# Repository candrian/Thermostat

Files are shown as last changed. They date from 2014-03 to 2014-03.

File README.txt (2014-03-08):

In the need of my new homemade energy saving fireplace (which boils water for the radiator) i designed and built a digital thermostat. The idea to design my own thermostat came when i came across with the following problem.
When i first fire the fireplace the water in the boiler around the fireplace is cool. After a few minutes the fireplace warms the water enough so that the water temp exceeds the thermostat limit. The thermostat changes state and drives an electric valve to move the water from the fireplace boiler to the radiators. The electric valve is slow enough and takes a few minutes to make a full turn. While the water is moving from the fireplace boiler to the radiators, circularly cool water is coming back in the fireplace boiler from the radiators. Τhe water temp in the fireplace boiler is getting cooler and after a few minutes falls under thermostat's limit. The thermostat changes state and stops the valve from driving the water to radiators. This happens again and again until the whole amount of water in the radiators is get warm. 
To prevent this problem from opening and closing the electric valve in so small time spaces i designed a thermostat that can delay the sample points. It check's the fireplace boiler temp and drives the electric valve once the water temp exceeds the thermostat limit. After that it waits for a half hour or more and then checks the water temp again.

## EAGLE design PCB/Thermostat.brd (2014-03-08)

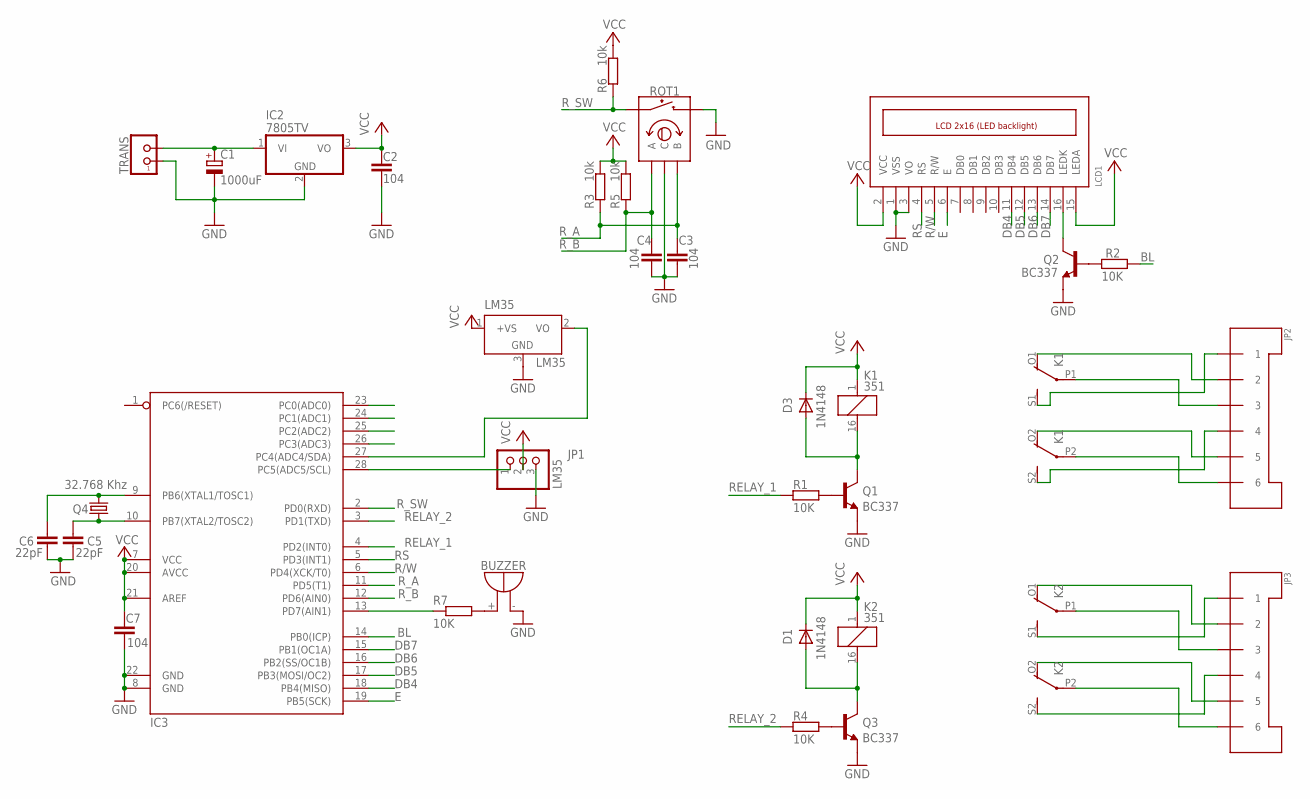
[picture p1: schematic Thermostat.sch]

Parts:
BUZZER: F/HMB
C1: 1000uF; C-TT2D13-SIDE
C2, C3, C4, C7: 104; C-22X6(FAKI)
C5, C6: 22pF; C-22X6(FAKI)
D1, D3: 1N4148; DO35-10
IC2: 7805TV; TO220V
IC3: ATMEGA-8-P; DIL28-3
JP1: LM35; 1X03
JP2, JP3: KLEMES_DELMAC_6
K1, K2: 351
LCD1: LCD-HD44780PINHEAD; HD44780-2X16-PINHEAD
LM35: LM35; TO-92
Q1, Q2, Q3: BC337; TO92-EBC
Q4: 32.768 Khz; TC38
R1, R2, R4, R7: 10K; R0270/10
R3, R5, R6: 10k; R0270/10
ROT1: ROTARY/5-PIN; 5-PIN/RP
TRANS: KLEMESX2

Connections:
BL: IC3.14 (PB0(ICP)), R2.2
DB4: IC3.18 (PB4(MISO)), LCD1.11 (DB4)
DB5: IC3.17 (PB3(MOSI/OC2)), LCD1.12 (DB5)
DB6: IC3.16 (PB2(SS/OC1B)), LCD1.13 (DB6)
DB7: IC3.15 (PB1(OC1A)), LCD1.14 (DB7)
E: IC3.19 (PB5(SCK)), LCD1.6 (E)
GND: BUZZER.-, C1.-, C2.2, C3.2, C4.2, C5.2, C6.2, C7.2, IC2.2 (GND), IC3.8 (GND), IC3.22 (GND), JP1.3, LCD1.1 (VSS), LCD1.3 (VO), LM35.3 (GND1), Q1.E, Q2.E, Q3.E, ROT1.C, ROT1.SW2, TRANS.1
unnamed: JP2.P$3 (3), K1.P1
unnamed: JP3.P$2 (2), K2.O1 (O)
unnamed: C1.+, IC2.1 (VI), TRANS.2
unnamed: D1.A, K2.16 (2), Q3.C
unnamed: C5.1, IC3.10 (PB7(XTAL2/TOSC2)), Q4.1
unnamed: Q3.B, R4.2
unnamed: JP3.P$6 (6), K2.P2
unnamed: BUZZER.+, R7.2
unnamed: IC3.13 (PD7(AIN1)), R7.1
unnamed: IC3.28 (PC5(ADC5/SCL)), JP1.1
unnamed: LCD1.16 (LEDK), Q2.C
unnamed: C6.1, IC3.9 (PB6(XTAL1/TOSC1)), Q4.2
unnamed: Q2.B, R2.1
unnamed: D3.A, K1.16 (2), Q1.C
unnamed: Q1.B, R1.2
unnamed: JP2.P$6 (6), K1.P2
unnamed: JP2.P$1 (1), K1.S1 (S)
unnamed: JP2.P$5 (5), K1.O2 (O)
unnamed: JP2.P$4 (4), K1.S2 (S)
unnamed: JP2.P$2 (2), K1.O1 (O)
unnamed: JP3.P$1 (1), K2.S1 (S)
unnamed: JP3.P$3 (3), K2.P1
unnamed: JP3.P$5 (5), K2.O2 (O)
unnamed: JP3.P$4 (4), K2.S2 (S)
unnamed: IC3.27 (PC4(ADC4/SDA)), LM35.2 (VO)
R/W: IC3.6 (PD4(XCK/T0)), LCD1.5 (R/W)
RELAY_1: IC3.4 (PD2(INT0)), R1.1
RELAY_2: IC3.3 (PD1(TXD)), R4.1
RS: IC3.5 (PD3(INT1)), LCD1.4 (RS)
R_A: C3.1, IC3.11 (PD5(T1)), R3.1, ROT1.B
R_B: C4.1, IC3.12 (PD6(AIN0)), R5.1, ROT1.A
R_SW: IC3.2 (PD0(RXD)), R6.1, ROT1.SW1
VCC: C2.1, C7.1, D1.C, D3.C, IC2.3 (VO), IC3.7 (VCC), IC3.20 (AVCC), IC3.21 (AREF), JP1.2, K1.1, K2.1, LCD1.2 (VCC), LCD1.15 (LEDA), LM35.1 (+VS), R3.2, R5.2, R6.2

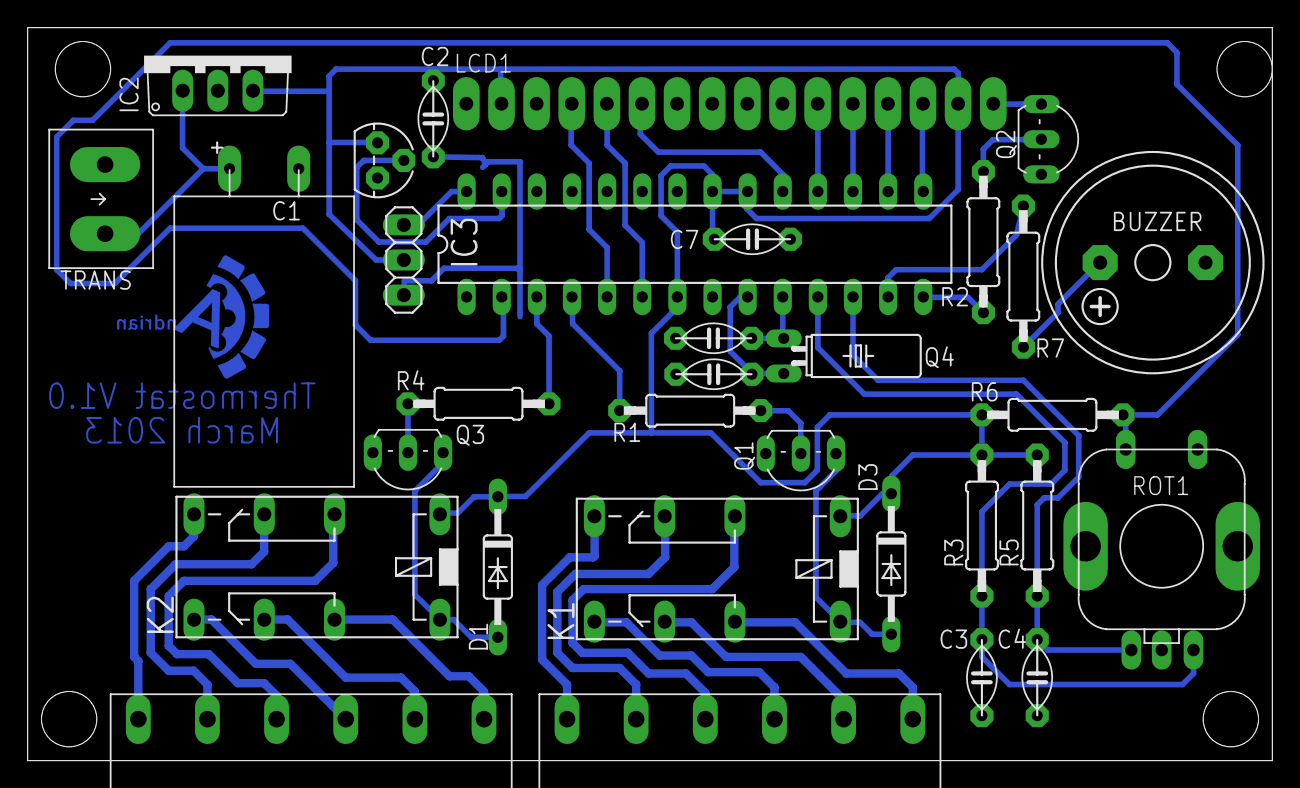
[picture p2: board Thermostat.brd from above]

Board: 2 copper layers, 90.0 x 53.0 mm, 33 parts (0 on the bottom side), 40 nets.

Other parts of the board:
U$1: CANDRIAN-LOGO/SMALL/BOTTOM

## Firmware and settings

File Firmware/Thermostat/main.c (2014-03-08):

/*
Thermostat
(c) Created by candrian on 3/27/13.

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
THE SOFTWARE IS PROVIDED "AS IS", WITHOUT WARRANTY OF ANY KIND, EXPRESS OR
IMPLIED, INCLUDING BUT NOT LIMITED TO THE WARRANTIES OF MERCHANTABILITY,
FITNESS FOR A PARTICULAR PURPOSE AND NONINFRINGEMENT. IN NO EVENT SHALL THE
AUTHORS OR COPYRIGHT HOLDERS BE LIABLE FOR ANY CLAIM, DAMAGES OR OTHER
LIABILITY, WHETHER IN AN ACTION OF CONTRACT, TORT OR OTHERWISE, ARISING FROM,
OUT OF OR IN CONNECTION WITH THE SOFTWARE OR THE USE OR OTHER DEALINGS IN
THE SOFTWARE.
*/

#include <avr/io.h>
#include <stdint.h>
#define F_CPU 8000000UL
#include <util/delay.h>     // Blocking delay functions
#include <avr/pgmspace.h>   // So we can store the 'font table' in ROM
#include <avr/interrupt.h>	// Interrupts and timers
#include <avr/eeprom.h>		// Date/time/pref backup in permanent EEPROM
#include <avr/sleep.h>      // Power save mode
#include <avr/wdt.h>


#include "main.h"

#include "lcd.h"
#include "lcd.c"

volatile    uint8_t minutes_set=0;
volatile    uint8_t hours_set=0;

volatile    uint8_t in_temp_set=0;
volatile    uint8_t pipe_temp_set=0;

volatile    uint16_t in_temp=0;
volatile    uint16_t pipe_temp=0;

volatile    uint8_t     rotary_state=NOTHING;
volatile    uint16_t    rotary_press_time=0;

volatile    uint8_t     menu_edit=OFF;

volatile    uint8_t     counter=0;
volatile    uint8_t     timer=OFF;

volatile    uint8_t     menu_timeout=0;
volatile    uint8_t     backlight_timeout=0;
volatile    uint8_t     backlight=ON;

volatile    uint8_t     in_temp_buffer[10];
volatile    uint8_t     pipe_temp_buffer[10];

volatile    uint8_t     buffer_pointer=0;

volatile    uint8_t     relay_pipe=OFF;
volatile    uint8_t     relay_in=OFF;


uint16_t adc_read(uint8_t sensor){
    ADMUX &= 0xf0;
    if (sensor==IN) {
        ADMUX   |=  (1<<MUX2);
    }else{
        ADMUX   |=  (1<<MUX2) | (1<<MUX0);
    }
    
    _delay_ms(1);
    ADCSRA  |=  _BV(ADSC);          //Start single conversion
    while(ADCSRA & _BV(ADSC));      //Wait to be completed
    
    return (ADC);
}

uint16_t adc_to_celsius(uint16_t adc){
    return((adc*500UL)/1023);
}

//Real Time Clock
ISR(TIMER2_OVF_vect){
    
    in_temp_buffer[buffer_pointer]=adc_to_celsius(adc_read(IN));
    pipe_temp_buffer[buffer_pointer]=adc_to_celsius(adc_read(PIPE));
    buffer_pointer++;
    if (buffer_pointer==9) buffer_pointer=0;
    
    if (backlight==ON && menu_edit==OFF) {
        backlight_timeout++;
        if (backlight_timeout==120) {
            backlight=OFF;
            backlight_timeout=0;
        }
    }
    
    if (menu_edit!=OFF) {
        menu_timeout++;
        
        if (menu_timeout==10) {
            
            eeprom_write_byte((uint8_t *)EE_IN_TEMP_1, in_temp_set);
            eeprom_write_byte((uint8_t *)EE_IN_TEMP_2, in_temp_set);
            
            eeprom_write_byte((uint8_t *)EE_PIPE_TEMP_1, pipe_temp_set);
            eeprom_write_byte((uint8_t *)EE_PIPE_TEMP_2, pipe_temp_set);
            
            eeprom_write_byte((uint8_t *)EE_SET_TIME_MINUTES_1, minutes_set);
            eeprom_write_byte((uint8_t *)EE_SET_TIME_MINUTES_2, minutes_set);
            
            eeprom_write_byte((uint8_t *)EE_SET_TIME_HOURS_1, hours_set);
            eeprom_write_byte((uint8_t *)EE_SET_TIME_HOURS_2, hours_set);
            
            menu_timeout=0;
            menu_edit=OFF;
            timer=OFF;
            
        }
        
    }else{
        menu_timeout=0;
    }
    
    if (timer==ON) {
        t.second++;
	}else{
        t.second=0;
        t.minute=0;
        t.hour=0;
    }
	//Minute passed
	if (t.second>=60) {
		t.second=0;
		t.minute++;
	}
	
	//Hour passed
	if (t.minute>=60) {
		t.minute=0;
		t.hour++;
	}
	
	//Day passed
	if (t.hour==99 && t.minute==60 && t.second==0) {
		t.hour=0;
        t.minute=0;
        t.second=0;
	}
    
}

//Main System
ISR(TIMER0_OVF_vect){
    
    //Enter setup menu or save
    if (rotary_state==BUTTON_LONG){

        if (menu_edit==OFF) {
            menu_edit=IN_TEMP;
            rotary_state=NOTHING;
        }else{
            //Save data
            eeprom_write_byte((uint8_t *)EE_IN_TEMP_1, in_temp_set);
            eeprom_write_byte((uint8_t *)EE_IN_TEMP_2, in_temp_set);
            
            eeprom_write_byte((uint8_t *)EE_PIPE_TEMP_1, pipe_temp_set);
            eeprom_write_byte((uint8_t *)EE_PIPE_TEMP_2, pipe_temp_set);
            
            eeprom_write_byte((uint8_t *)EE_SET_TIME_MINUTES_1, minutes_set);
            eeprom_write_byte((uint8_t *)EE_SET_TIME_MINUTES_2, minutes_set);
            
            eeprom_write_byte((uint8_t *)EE_SET_TIME_HOURS_1, hours_set);
            eeprom_write_byte((uint8_t *)EE_SET_TIME_HOURS_2, hours_set);
            
            menu_edit=OFF;
            timer=OFF;
            rotary_state=NOTHING;
        }
    }
    
    //Rotate menu setup
    if (rotary_state==BUTTON) {
        if (menu_edit!=OFF) {
            menu_edit++;
            if (menu_edit==5) menu_edit=IN_TEMP;
        }
        rotary_state=NOTHING;
    }
    
    if (menu_edit==IN_TEMP) {
        if (rotary_state==RIGHT){
            if (in_temp_set<140) {
                in_temp_set++;
            }else{
                beep();
            }
        }else if (rotary_state==LEFT){
            if (in_temp_set!=0) {
                in_temp_set--;
            }else{
                beep();
            }
        }
        rotary_state=NOTHING;
    }
    
    if (menu_edit==PIPE_TEMP) {
        if (rotary_state==RIGHT){
            if (pipe_temp_set<140) {
                pipe_temp_set++;
            }else{
                beep();
            }
        }else if (rotary_state==LEFT){
            if (pipe_temp_set!=0) {
                pipe_temp_set--;
            }else{
                beep();
            }
        }
        rotary_state=NOTHING;
    }

    if (menu_edit==SET_TIME) {
        if (rotary_state==RIGHT) {
            if (minutes_set==59) {
                minutes_set=0;
                hours_set++;
            }else{
                minutes_set++;
                if (hours_set==99 && minutes_set==59) {
                    hours_set=0;
                    minutes_set=0;
                }
            }
            rotary_state=NOTHING;
        }else if (rotary_state==LEFT){
            if (minutes_set==0 && hours_set!=0) {
                hours_set--;
                minutes_set=59;
            }else if (minutes_set==0 && hours_set==0){
                beep();
            }else{
                minutes_set--;
            }
            rotary_state=NOTHING;
        }else if (rotary_state==BUTTON){
            rotary_state=NOTHING;
        }
    }
    
}

ISR(TIMER1_OVF_vect) {
    
    counter++;
    if (counter>100) {
        counter=0;
    }
    
    print_temp(0,0,IN);
    print_temp(0,1,PIPE);
    
    if (menu_edit==IN_TEMP) {
        if (counter<50) {
            print_set_in_temp(6,0);
        }else{
            lcd_gotoxy(6,0);
            lcd_puts("   ");
        }
    }else{
        print_set_in_temp(6,0);
    }
    
    if (menu_edit==PIPE_TEMP) {
        if (counter<50) {
            print_set_pipe_temp(6,1);
        }else{
            lcd_gotoxy(6,1);
            lcd_puts("   ");
        }
    }else{
        print_set_pipe_temp(6,1);
    }
    
    if (relay_pipe==OFF) {
        lcd_gotoxy(10,1);
        lcd_putc('F');
        PORT_RELAY  &= ~(1<<RELAY_1);
    }else{
        lcd_gotoxy(10,1);
        lcd_putc('N');
        PORT_RELAY  |= (1<<RELAY_1);
    }
    
    if (relay_in==OFF) {
        lcd_gotoxy(10,0);
        lcd_putc('F');
        PORT_RELAY  &= ~(1<<RELAY_2);
    }else{
        lcd_gotoxy(10,0);
        lcd_putc('N');
        PORT_RELAY  |= (1<<RELAY_2);
    }
    
    if (menu_edit==SET_TIME) {
        if (counter<50) {
            print_set_time(12,1);
        }else{
            lcd_gotoxy(12,1);
            lcd_puts("     ");
        }
    }else{
        print_set_time(12,1);
    }
    
    print_time(12,0);
    
    if (backlight==ON) {
        PORT_BACKLIGHT  |=  (1<<BACKLIGHT);
    }else{
        PORT_BACKLIGHT  &=  ~(1<<BACKLIGHT);
    }
}

ISR(PCINT2_vect) {
    //Disable Pin interrupts
    PCICR       &=  ~(1<<PCIE2);
    //Allow other interrupts
    sei();
    //Debounce
    _delay_ms(DEBOUNCE);
    
    backlight=ON;
    
    if ((PIN_ROTARY & (1<<R_SW))==0) {
        rotary_state=BUTTON;
        menu_timeout=0;
        if (menu_edit!=OFF ) {
            beep();
        }
        while ((PIN_ROTARY & (1<<R_SW))==0) {
            
            if (rotary_press_time<151) {
                rotary_press_time++;
                _delay_ms(5);
            }
            
            if (rotary_press_time==150) {
                beep();
                _delay_ms(100);
                beep();
                rotary_state=BUTTON_LONG;
            }
        }
        rotary_press_time=0;

        PCICR       |=  (1<<PCIE2);
        return;
    }
    //Filter bounce
    if ((PIN_ROTARY & (1<<R_A))!=0) {
        //Enable Pin Interrupts
        PCICR       |=  (1<<PCIE2);
        return;
    }

    if ((PIN_ROTARY & (1<<R_B))==0) {
        //left
        rotary_state=LEFT;
        menu_timeout=0;
    }else{
        //right
        rotary_state=RIGHT;
        menu_timeout=0;
    }
    
    PCICR       |=  (1<<PCIE2);
}

void clock_init(){
    // Turn on the RTC by selecting the external 32khz crystal
	// 32.768 / 128 = 256 which is exactly an 8-bit timer overflow
	ASSR |= (1<<AS2);               //Timer/Counter 2 clocked from a crystal to the Timer Oscillator 1 (TOSC1) pin
	TCCR2B = (1<<CS22) | (1<<CS20); //clkT2S/128 (From prescaler)
    
    //Enable Timer/Counter2 Overflow interrupt
	TIMSK2 |= (1<<TOIE2);
    
}

void ports_init(){
    
    DDR_RELAY       |= (1<<RELAY_1) | (1<<RELAY_2);
    PORT_RELAY      &= ~(1<<RELAY_1) & ~(1<<RELAY_2);
    
    DDR_BEEPER      |=  (1<<BEEPER);
    PORT_BEEPER     &=  ~(1<<BEEPER);
    
    DDR_BACKLIGHT   |=  (1<<BACKLIGHT);
    PORT_BACKLIGHT  |=  (1<<BACKLIGHT);
    
    DDR_ROTARY      &=  ~(1<<R_A) & ~(1<<R_B) & ~(R_SW);
    
    //Enable pin change interrupt PCINT20
    PCMSK2      |=  (1<<PCINT21) | (1<<PCINT16);
    PCICR       |=  (1<<PCIE2); 
    
    TCCR0B  =   (1<<CS01)|(1<<CS00);    //f/64=31.250khz
    TIMSK0  =   (1<<TOIE0);             //Enable overflow interrupt
    
    TCCR1B |=   (1<<CS10);                  //clkI/O/1 (No prescaling)
    TIMSK1 |=   (1<<TOIE1);                 //Timer/Counter1 Overflow interrupt
}

void beep(){
    PORT_BEEPER     |=  (1<<BEEPER);
    _delay_ms(20);
    PORT_BEEPER     &=  ~(1<<BEEPER);

}

void adc_init(){
    DDRC    &=~ (1<<LM35_IN);   //Input for LM35
    DDRC    &=~ (1<<LM35_PIPE);  //Input for LM35

    ADMUX   =   (1<<REFS0);                             //AVCC with external capacitor at AREF pin
    ADMUX   |=  (1<<MUX2);                          //Select ADC1 channel
    
    ADCSRA  =   (1<<ADPS2) | (1<<ADPS1) | (1<<ADPS0);   //Set prescaler to 128 16MHz/128 = 125kHz
    ADCSRA  |=   (1<<ADEN);                              //Enable ADC
}

void lcd_print_decimal(uint8_t value, uint8_t type, uint8_t digits){
    
    uint8_t temp=0;
    uint8_t hundreds=0;
    uint8_t dozens=0;
    uint8_t units=0;
    
    hundreds=value/0x64;
    temp=value%0x64;
    
    dozens=temp/0x0a;
    units=temp%0x0a;
    
    if (type!=TIME) {
        if (hundreds!=0) {
            lcd_putc(hundreds+0x30);
        }else{
            
            lcd_putc(' ');
        }
    }
    if (digits==1) {
        lcd_putc(units+0x30);
    }else{
        lcd_putc(dozens+0x30);
        lcd_putc(units+0x30);
    }

}

void print_time(uint8_t x, uint8_t y){
    lcd_gotoxy(x,y);
    lcd_print_decimal(t.hour,TIME,1);
    lcd_putc(':');
    lcd_print_decimal(t.minute,TIME,2);    
}

void print_set_time(uint8_t x, uint8_t y){
    lcd_gotoxy(x,y);
    lcd_print_decimal(hours_set,TIME,1);
    lcd_putc(':');
    lcd_print_decimal(minutes_set,TIME,2);
}

void print_set_in_temp(uint8_t x, uint8_t y){
    lcd_gotoxy(x,y);
    lcd_print_decimal(in_temp_set, TEMP,2);
    lcd_putc(DEGREE);
}

void print_set_pipe_temp(uint8_t x, uint8_t y){
    lcd_gotoxy(x,y);
    lcd_print_decimal(pipe_temp_set, TEMP,2);
    lcd_putc(DEGREE);
}

void print_temp(uint8_t x, uint8_t y, uint8_t sensor){
    
    lcd_gotoxy(x,y);
    
    if (sensor==IN) {
        lcd_print_decimal(in_temp, TEMP,2);
    }else{
        lcd_print_decimal(pipe_temp, TEMP,2);
    }
    lcd_putc(DEGREE);
    lcd_putc('C');
}

int main(void){
    
    uint16_t temp1=0, temp2=0, i;
    lcd_init(LCD_DISP_ON);

    _delay_ms(500);

    clock_init();
    ports_init();
    adc_init();
    
    lcd_clrscr();
    sei();
    beep();
    _delay_ms(100);
    beep();
    
    for (i=0;i<10;i++){
        in_temp_buffer[i]=21;
        pipe_temp_buffer[i]=21;
    }
        
    temp1=eeprom_read_byte((uint8_t *)EE_IN_TEMP_1);
    temp2=eeprom_read_byte((uint8_t *)EE_IN_TEMP_2);
    
    if (temp1==temp2) {
        in_temp_set=temp1;
    }else{
        eeprom_write_byte((uint8_t *)EE_IN_TEMP_1, 0);
        eeprom_write_byte((uint8_t *)EE_IN_TEMP_2, 0);
    }
    
    temp1=eeprom_read_byte((uint8_t *)EE_PIPE_TEMP_1);
    temp2=eeprom_read_byte((uint8_t *)EE_PIPE_TEMP_2);
    
    if (temp1==temp2) {
        pipe_temp_set=temp1;
    }else{
        eeprom_write_byte((uint8_t *)EE_PIPE_TEMP_1, 0);
        eeprom_write_byte((uint8_t *)EE_PIPE_TEMP_2, 0);
    }
    
    temp1=eeprom_read_byte((uint8_t *)EE_SET_TIME_MINUTES_1);
    temp2=eeprom_read_byte((uint8_t *)EE_SET_TIME_MINUTES_2);
    
    if (temp1==temp2) {
        minutes_set=temp1;
    }else{
        eeprom_write_byte((uint8_t *)EE_SET_TIME_MINUTES_1, 0);
        eeprom_write_byte((uint8_t *)EE_SET_TIME_MINUTES_2, 0);
    }
    
    temp1=eeprom_read_byte((uint8_t *)EE_SET_TIME_HOURS_1);
    temp2=eeprom_read_byte((uint8_t *)EE_SET_TIME_HOURS_2);
    
    if (temp1==temp2) {
        hours_set=temp1;
    }else{
        eeprom_write_byte((uint8_t *)EE_SET_TIME_HOURS_1, 0);
        eeprom_write_byte((uint8_t *)EE_SET_TIME_HOURS_2, 0);
    }
    
    while (1) {
        
        temp1=0;
        temp2=0;
        
        for (i=0; i<10; i++) {
            temp1+=in_temp_buffer[i];
            temp2+=pipe_temp_buffer[i];
        }
        
        in_temp=temp1/10;
        pipe_temp=temp2/10;
        
        if (timer==OFF) {
            if (pipe_temp>=pipe_temp_set) {
                relay_pipe=ON;
                timer=ON;
            }else{
                relay_pipe=OFF;
            }
        }
        
        if (in_temp<=in_temp_set) {
            relay_in=ON;
        }else{
            relay_in=OFF;
        }
        
    
        if (t.minute==minutes_set && t.hour==hours_set) {
            timer=OFF;
        }
        
    }

    return 0;
}

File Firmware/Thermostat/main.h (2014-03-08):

#define BACKLIGHT       PB0
#define PORT_BACKLIGHT  PORTB
#define DDR_BACKLIGHT   DDRB


#define LM35_IN         PC4
#define LM35_PIPE       PC5
#define PORT_LM35       PORTC
#define DDR_LM35        DDRC

#define IN          0
#define PIPE        1

#define DEBOUNCE    0

#define R_A         PD5
#define R_B         PD6
#define R_SW        PD0

#define PORT_ROTARY PORTD
#define PIN_ROTARY  PIND
#define DDR_ROTARY  DDRD

#define PORT_BEEPER PORTD
#define DDR_BEEPER  DDRD
#define BEEPER      PD7

#define PORT_RELAY  PORTD
#define DDR_RELAY   DDRD
#define RELAY_1     PD2
#define RELAY_2     PD1

#define DEGREE      223 //Degree symbol

#define TIME        0
#define TEMP        1

#define NOTHING     0
#define RIGHT       1
#define LEFT        2
#define BUTTON      3
#define BUTTON_LONG 4

#define ON  0
#define OFF 1

#define IN_TEMP     2
#define PIPE_TEMP   3
#define SET_TIME    4

#define EE_IN_TEMP_1            0
#define EE_IN_TEMP_2            1
#define EE_PIPE_TEMP_1          2
#define EE_PIPE_TEMP_2          3
#define EE_SET_TIME_MINUTES_1   4
#define EE_SET_TIME_MINUTES_2   5
#define EE_SET_TIME_HOURS_1     6
#define EE_SET_TIME_HOURS_2     7

//Time struct
typedef struct{
	volatile uint8_t second; 
	volatile uint8_t minute;
	volatile uint8_t hour;
}time;
time t;
